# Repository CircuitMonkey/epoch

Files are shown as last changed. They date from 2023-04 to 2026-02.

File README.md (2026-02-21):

# Epoch 1
A 16 channel hand-held vibrator controller (haptic field emitter). With LCD Touch Screen and SD Card reader. Replaced by [Epoch-2](https://github.com/CircuitMonkey/epoch-2)

## Features
 - TFT Touch Display - 320x240 - 3.2inch - SPI Type - Resistive Touch
 - Adafruit Huzzah32 ESP Controller Board (#3405)
 - TLC59401RHB SPI PWM Channel Driver
 - LiPo Battery - 62mm x 50mm, 2500mAH, Adafruit (#328)
 - Molex MiniFitJr type connectors with custom cables.
 - Programmed in Arduino
 - Approximate size of original Apple iPod.

## Dev Notes
 - Huzzah has on-board LiPo charger which made integration simple.
 - Choice of Molex MinifitJr type connectors was cumbersome in use.
 - Choice of Molex MinifitJr type connectors made custom cable fabrication time consuming.
 - This platform performed well for almost a year, before Epoch-2 developed.
 - Never used SD card. Removed off future designs.
 - Choice of TLC59401RHB was cumbersome in coding. Moved to I2C type PWM chip in future Epoch designs.
 - Choice of TLC59401RHB limited motor size as only could source 120mA per channel. Added power FETs to future Epoch designs.

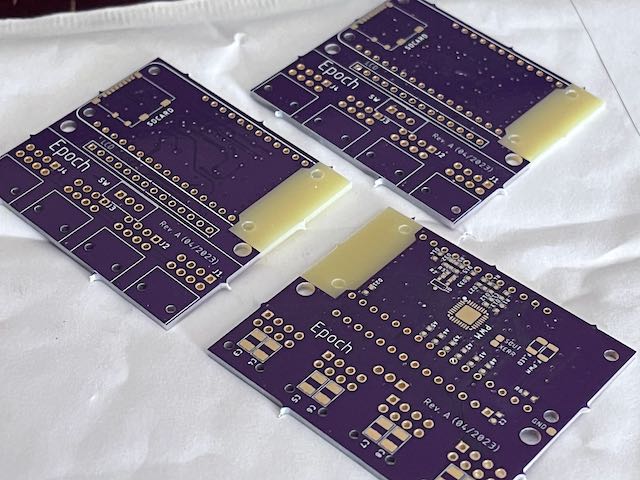
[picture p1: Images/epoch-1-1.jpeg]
Epoch 1 - PCBs (from OshPark.com)

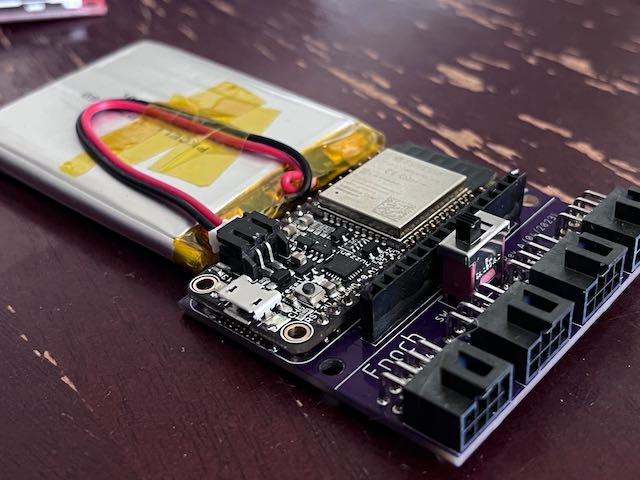
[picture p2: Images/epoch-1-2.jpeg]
Epoch 1 - Board and Battery

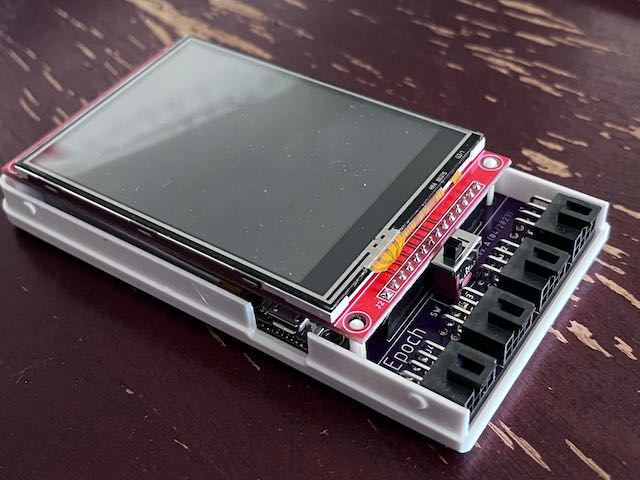
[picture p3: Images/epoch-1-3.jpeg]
Epoch 1 - Board, Battery, LCD and Chassis Bottom

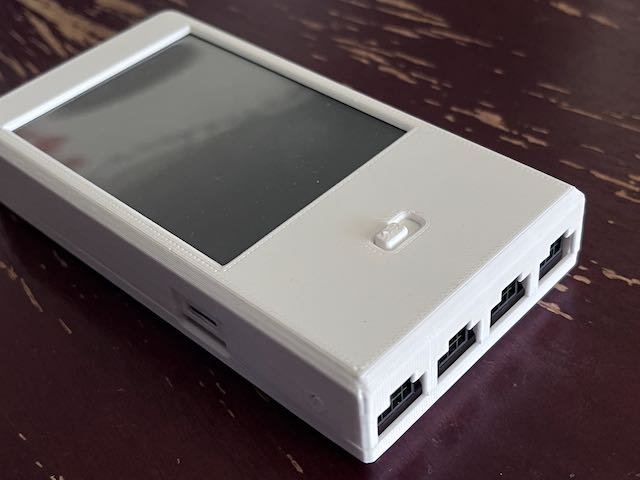
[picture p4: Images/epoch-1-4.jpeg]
Epoch 1 - Assembled Unit

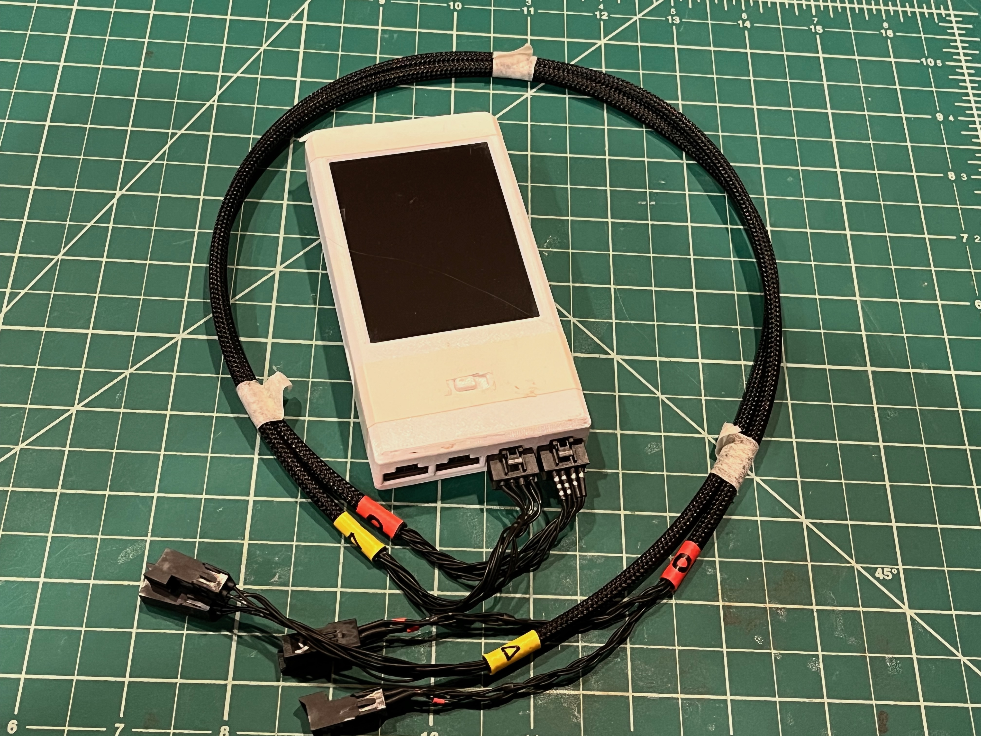
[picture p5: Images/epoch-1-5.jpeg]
Epoch 1 - Assembled Unit with Cables

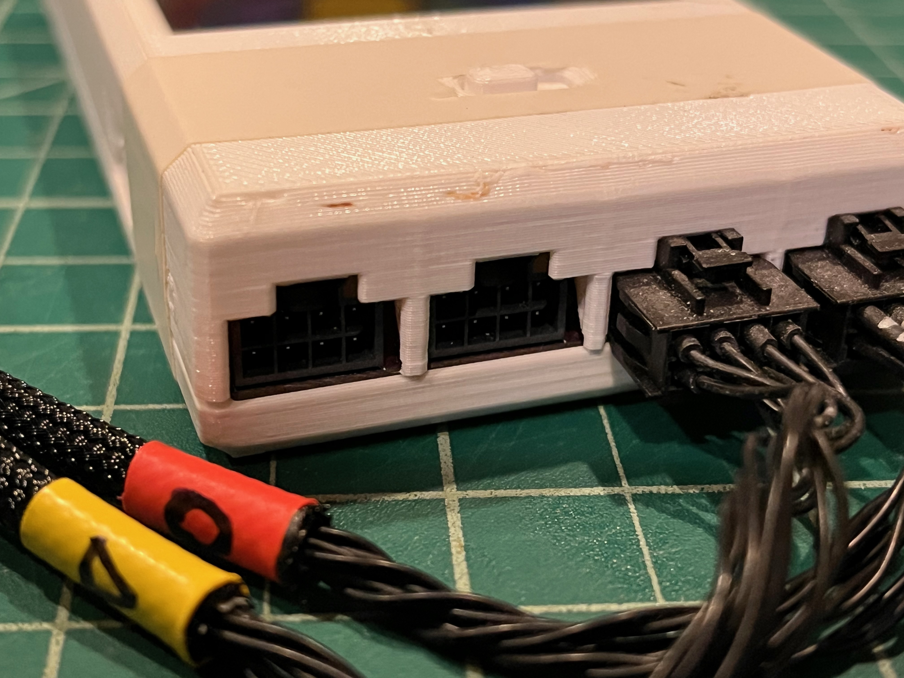
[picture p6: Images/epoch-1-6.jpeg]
Epoch 1 - Connectors Detail

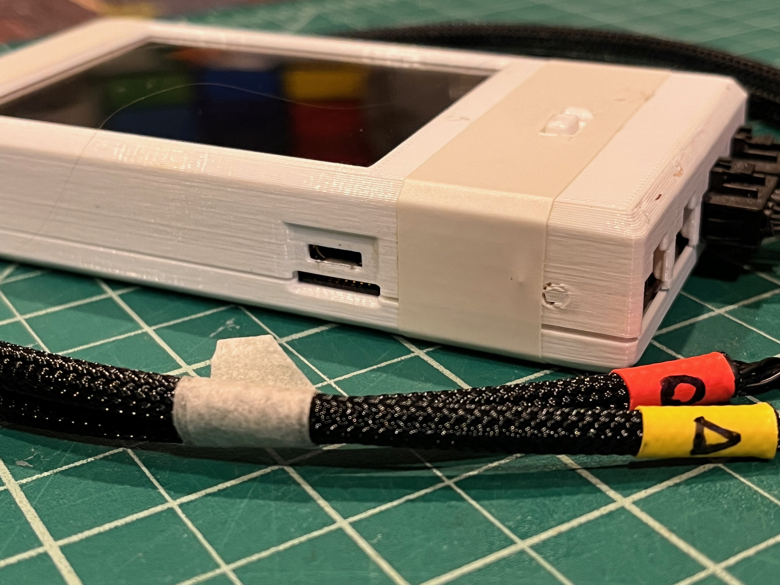
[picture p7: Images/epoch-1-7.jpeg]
Epoch 1 - USB and SC-Card Slot

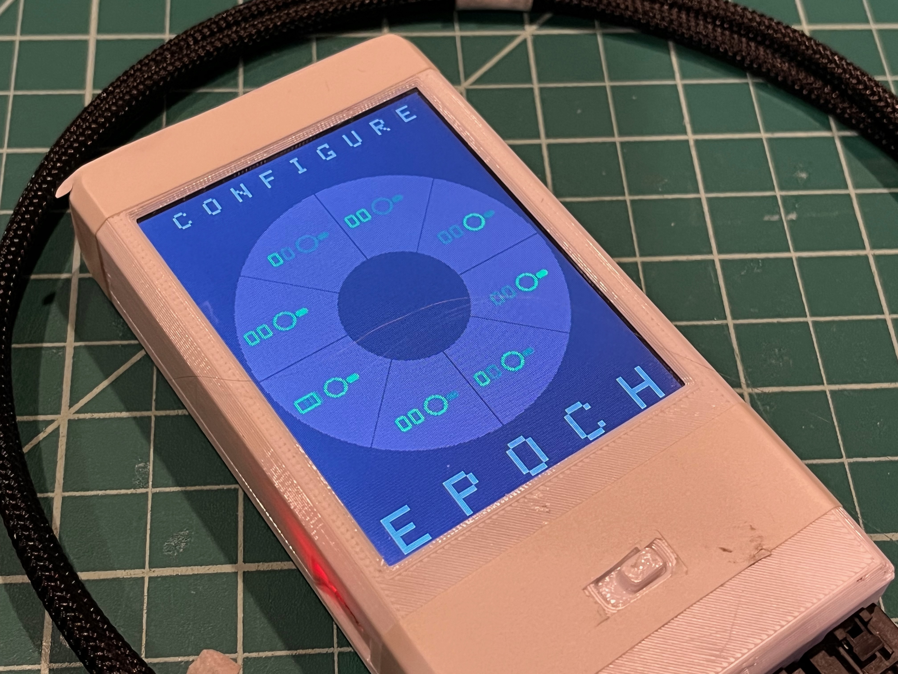
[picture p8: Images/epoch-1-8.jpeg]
Epoch 1 - Configuration Screen

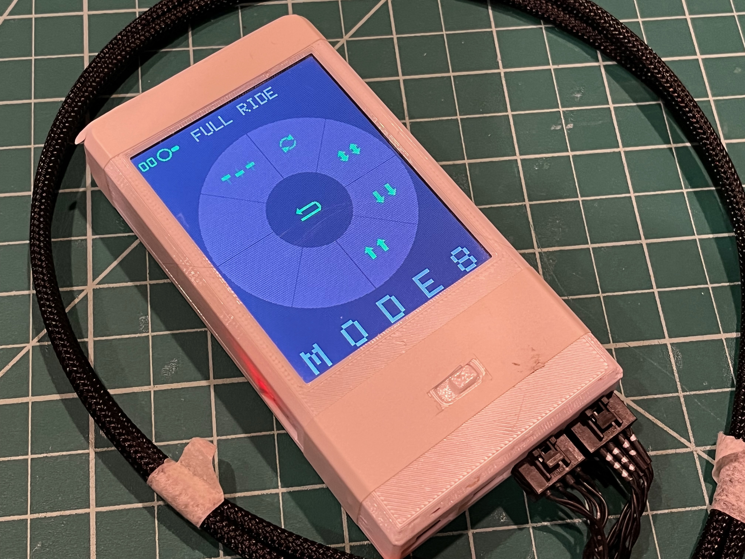
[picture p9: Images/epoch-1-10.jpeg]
Epoch 1 - Mode Selection

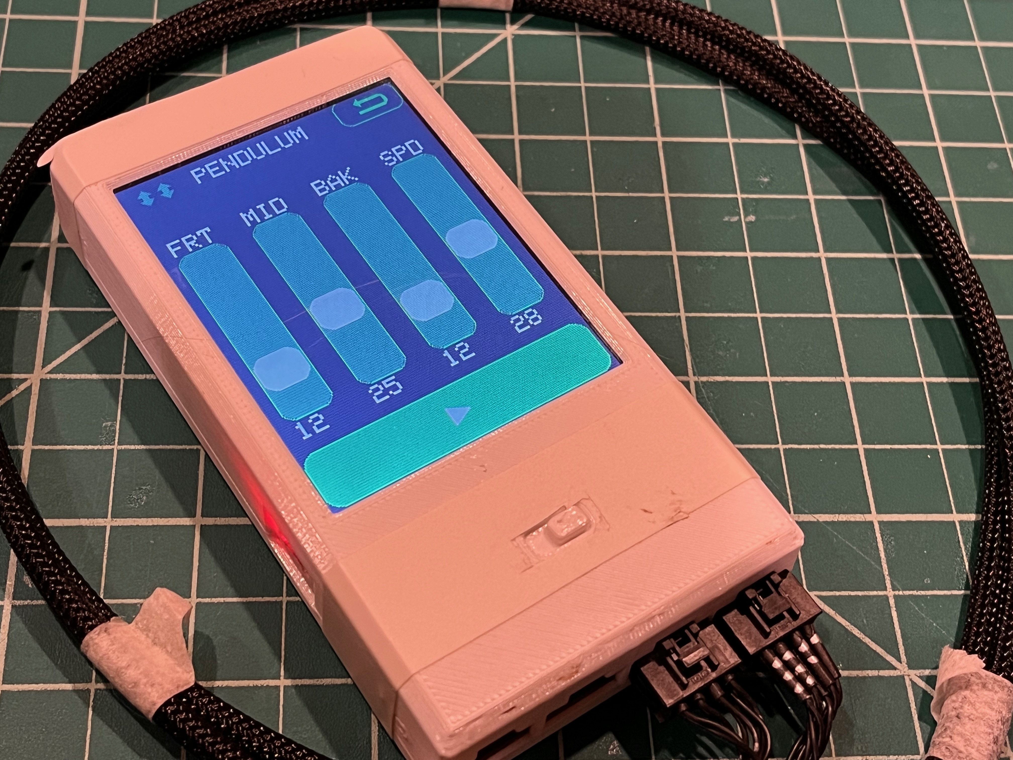
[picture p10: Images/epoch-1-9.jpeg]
Epoch 1 - Pendultum Mode


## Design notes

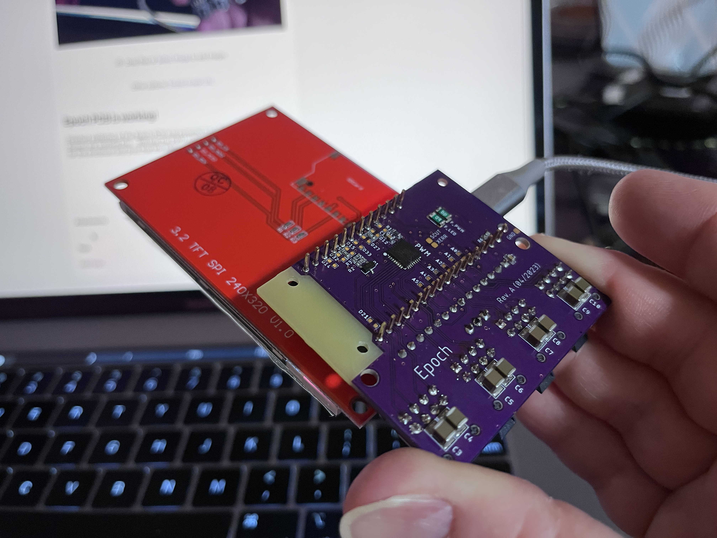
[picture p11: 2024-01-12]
Documents/photos/epoch-bottom-tft.jpeg

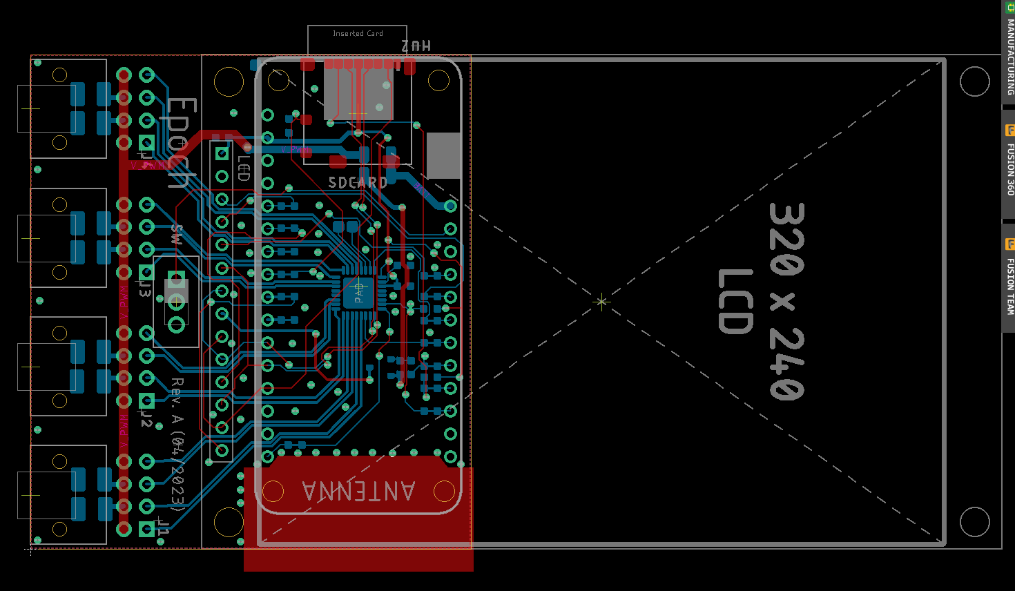
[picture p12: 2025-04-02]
Documents/pcb-layers.png

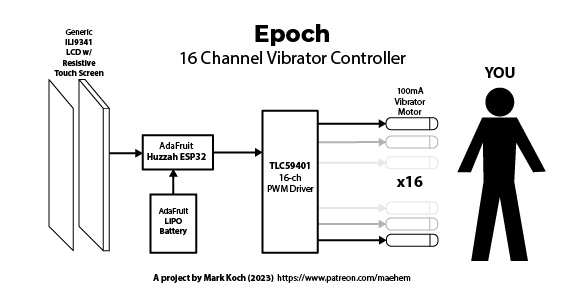
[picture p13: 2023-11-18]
Documents/epoch-block-diagram.png

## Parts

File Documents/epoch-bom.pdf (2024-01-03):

epoch-bom-rev-a

## Circuit Monkey

Epoch – 16-ch Vibe Controller | Rev. A (04/2023)
Part | Value | Package | Description
C1 | 0.1uF | 0603-CAP | Capacitor
C2 | 0.1uF | 0603-CAP | Capacitor
C3 | 22uF/16V | 1210-CAP | Capacitor
C4 | 22uF/16V | 1210-CAP | Capacitor
C5 | 22uF/16V | 1210-CAP | Capacitor
C6 | 22uF/16V | 1210-CAP | Capacitor
C7 | 22uF/16V | 1210-CAP | Capacitor
C8 | 22uF/16V | 1210-CAP | Capacitor
C9 | 22uF/16V | 1210-CAP | Capacitor
C10 | 22uF/16V | 1210-CAP | Capacitor
R1 | 330 | 0603-RES | Resistor
R2 | 100K | 0603-RES | Resistor
R3 | 1K | 0603-RES | Resistor
R4 | 10K | 0603-RES | Resistor
R5 | 100K | 0603-RES | Resistor
R6 | 10K | 0603-RES | Resistor
F_LED | Belfuse 0ZCJxxx | BELFUSE-1206 | Fuse, 100mA
F_PWM | Belfuse 0ZCJxxx | BELFUSE-1206 | Fuse, 750mA
Q1 | P-FET, 20V, 2A | SOT-23 | P-FET (PFET)
PWM | 16-CH PWM Driver QFN-32 | 16-CHANNEL LED DRIVER
J1 | | MOLEX-105314-XX08 | 8-pin, Nanofit, 2-ROW, RA, SMD
J2 | | MOLEX-105314-XX08 | 8-pin, Nanofit, 2-ROW, RA, SMD
J3 | | MOLEX-105314-XX08 | 8-pin, Nanofit, 2-ROW, RA, SMD
J4 | | MOLEX-105314-XX08 | 8-pin, Nanofit, 2-ROW, RA, SMD
LCD-SCKTHeader | Header, 14P, VERT, FEM
SDCARD MOLEX_1040310811MOLEX_1040310811_USD | MICRO-SD
SW | SPDT | CK_TS01C | Switch,Slide, SPDT, PCB
HUZ | Huzzah, ESP32 | ADAFRUIT_HUZZAH32 | AdaFruit Huzzah32
LCD | LCD,320x240,3.2in LCD-320X240-DIANN-3.2 | LCD, 320x240, Touch, 3.2-inch
| | | Parts Cost :

Cables
Conn | Molex Housing, 8P
Wire | Wire with crimped pin

COST01 COST10 COST100 HAVE MFR | MPN
$0.12 | $0.09 | $0.05
$0.12 | $0.09 | $0.05
$0.25 | $0.20 | $0.10
$0.25 | $0.20 | $0.10
$0.25 | $0.20 | $0.10
$0.25 | $0.20 | $0.10
$0.25 | $0.20 | $0.10
$0.25 | $0.20 | $0.10
$0.25 | $0.20 | $0.10
$0.25 | $0.20 | $0.10
$0.10 | $0.05 | $0.02
$0.10 | $0.05 | $0.02
$0.10 | $0.05 | $0.02
$0.10 | $0.05 | $0.02
$0.10 | $0.05 | $0.02
$0.10 | $0.05 | $0.02
$0.22 | $0.14 | $0.10 Mouser | Belfuse | 0ZCJ0010FF2E
$0.25 | $0.23 | $0.19 Mouser | Belfuse | 0ZCJ0075FF2C
$0.45 | $0.35 | $0.25 Mouser | Generic | FDN340P
$3.50 | $3.10 | $2.60 Mouser | Texas Instruments TLC59401RHB
$2.00 | $1.70 | $1.50 Mouser | Molex
$2.00 | $1.70 | $1.50 Mouser | Molex
$2.00 | $1.70 | $1.50 Mouser | Molex
$2.00 | $1.70 | $1.50 Mouser | Molex
$0.30 | $0.20 | $0.10 | Tayda
$2.25 | $1.90 | $1.60 | Molex | 1040310811
$5.00 | $4.00 | $2.00 | C&K | TS01C*
$20.00 | $18.00 | $16.00 Mouser | AdaFruit | 3405
$16.00 | $14.00 | $8.00 | DIANN
$58.81 $50.80 | $37.86
$0.30 | $0.30 | $0.25 | Molex | 105308-1208
$0.19 | $0.19 | $0.16 | Molex | 105300-1200

### LINK

1210/47uF/10V have

### ZXMP3A13FTA

https://www.mouser.com/ProductDetail/Texas-Instruments/TLC59401RHBR

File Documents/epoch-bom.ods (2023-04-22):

Circuit Monkey
Epoch – 16-ch Vibe Controller |  |  | Rev. A (04/2023)
Part | Value | Package | Description | COST01 | COST10 | COST100 | HAVE | MFR | MPN | LINK
C1 | 0.1uF | 0603-CAP | Capacitor | $0.12 | $0.09 | $0.05
C2 | 0.1uF | 0603-CAP | Capacitor | $0.12 | $0.09 | $0.05
C3 | 22uF/16V | 1210-CAP | Capacitor | $0.25 | $0.20 | $0.10
C4 | 22uF/16V | 1210-CAP | Capacitor | $0.25 | $0.20 | $0.10
C5 | 22uF/16V | 1210-CAP | Capacitor | $0.25 | $0.20 | $0.10 |  |  |  | 1210/47uF/10V have
C6 | 22uF/16V | 1210-CAP | Capacitor | $0.25 | $0.20 | $0.10
C7 | 22uF/16V | 1210-CAP | Capacitor | $0.25 | $0.20 | $0.10
C8 | 22uF/16V | 1210-CAP | Capacitor | $0.25 | $0.20 | $0.10
C9 | 22uF/16V | 1210-CAP | Capacitor | $0.25 | $0.20 | $0.10
C10 | 22uF/16V | 1210-CAP | Capacitor | $0.25 | $0.20 | $0.10
R1 | 330 | 0603-RES | Resistor | $0.10 | $0.05 | $0.02
R2 | 100K | 0603-RES | Resistor | $0.10 | $0.05 | $0.02
R3 | 1K | 0603-RES | Resistor | $0.10 | $0.05 | $0.02
R4 | 10K | 0603-RES | Resistor | $0.10 | $0.05 | $0.02
R5 | 100K | 0603-RES | Resistor | $0.10 | $0.05 | $0.02
R6 | 10K | 0603-RES | Resistor | $0.10 | $0.05 | $0.02
F_LED | Belfuse 0ZCJxxx | BELFUSE-1206 | Fuse, 100mA | $0.22 | $0.14 | $0.10 | Mouser | Belfuse | 0ZCJ0010FF2E
F_PWM | Belfuse 0ZCJxxx | BELFUSE-1206 | Fuse, 750mA | $0.25 | $0.23 | $0.19 | Mouser | Belfuse | 0ZCJ0075FF2C
Q1 | P-FET, 20V, 2A | SOT-23 | P-FET (PFET) | $0.45 | $0.35 | $0.25 | Mouser | Generic | FDN340P | ZXMP3A13FTA
PWM | 16-CH PWM Driver | QFN-32 | 16-CHANNEL LED DRIVER | $3.50 | $3.10 | $2.60 | Mouser | Texas Instruments | TLC59401RHB | https://www.mouser.com/ProductDetail/Texas-Instruments/TLC59401RHBR
J1 |  | MOLEX-105314-XX08 | 8-pin, Nanofit, 2-ROW, RA, SMD | $2.00 | $1.70 | $1.50 | Mouser | Molex
J2 |  | MOLEX-105314-XX08 | 8-pin, Nanofit, 2-ROW, RA, SMD | $2.00 | $1.70 | $1.50 | Mouser | Molex
J3 |  | MOLEX-105314-XX08 | 8-pin, Nanofit, 2-ROW, RA, SMD | $2.00 | $1.70 | $1.50 | Mouser | Molex
J4 |  | MOLEX-105314-XX08 | 8-pin, Nanofit, 2-ROW, RA, SMD | $2.00 | $1.70 | $1.50 | Mouser | Molex
LCD-SCKT | Header |  | Header, 14P, VERT, FEM | $0.30 | $0.20 | $0.10 |  | Tayda
SDCARD | MOLEX_1040310811 | MOLEX_1040310811_USD | MICRO-SD | $2.25 | $1.90 | $1.60 |  | Molex | 1040310811
SW | SPDT | CK_TS01C | Switch,Slide, SPDT, PCB | $5.00 | $4.00 | $2.00 |  | C&K | TS01C*
HUZ | Huzzah, ESP32 | ADAFRUIT_HUZZAH32 | AdaFruit Huzzah32 | $20.00 | $18.00 | $16.00 | Mouser | AdaFruit | 3405
LCD | LCD,320x240,3.2in | LCD-320X240-DIANN-3.2 | LCD, 320x240, Touch, 3.2-inch | $16.00 | $14.00 | $8.00 |  | DIANN
 |  |  | Parts Cost : | $58.81 | $50.80 | $37.86
Cables
Conn |  |  | Molex Housing, 8P | $0.30 | $0.30 | $0.25 |  | Molex | 105308-1208
Wire |  |  | Wire with crimped pin | $0.19 | $0.19 | $0.16 |  | Molex | 105300-1200

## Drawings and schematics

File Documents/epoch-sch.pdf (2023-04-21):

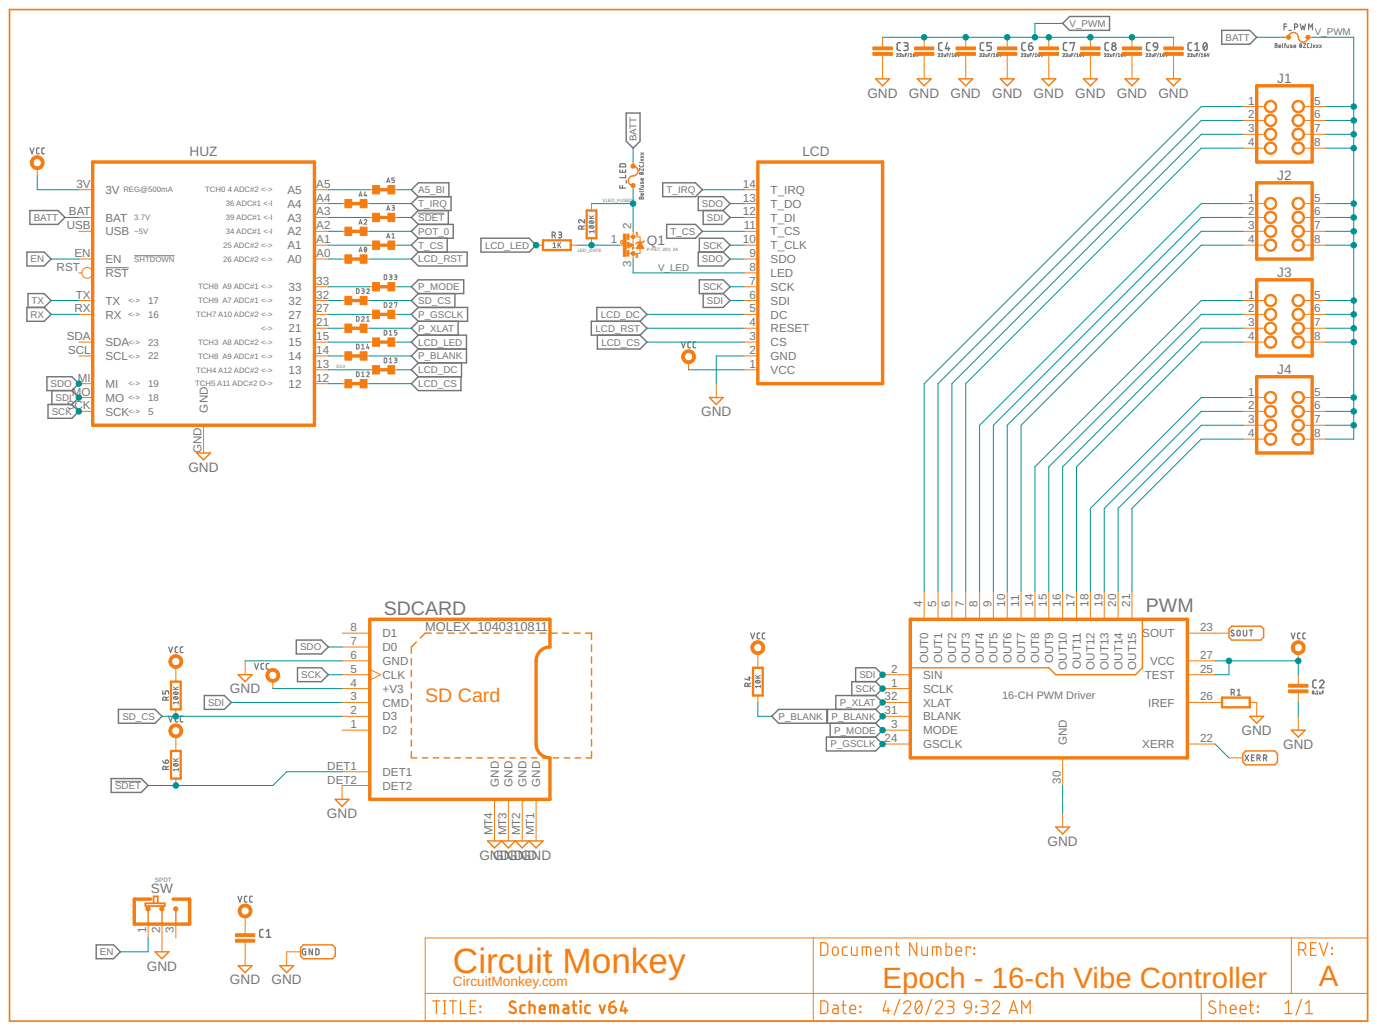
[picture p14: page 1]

GND GND GND GND

34 ADC#1 <-I 39 ADC#1 <-I 36 ADC#1 <-I TCH0 4 ADC#2 <->

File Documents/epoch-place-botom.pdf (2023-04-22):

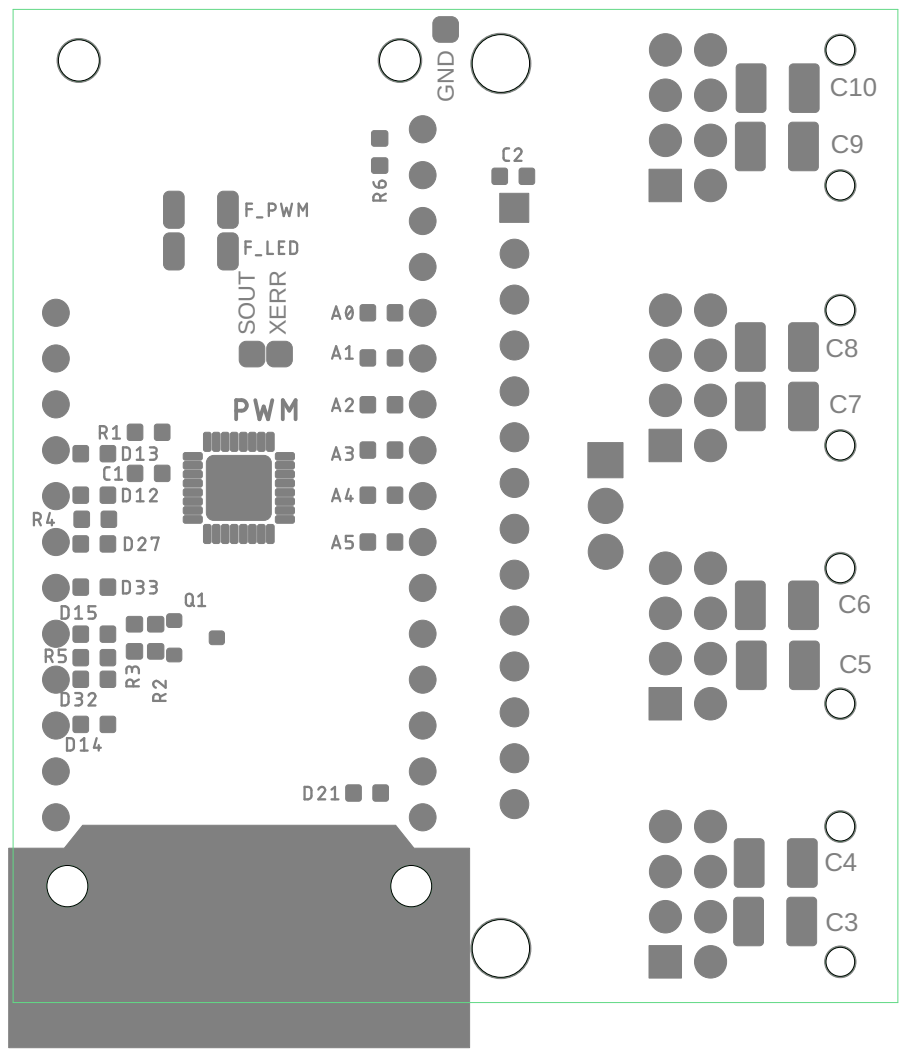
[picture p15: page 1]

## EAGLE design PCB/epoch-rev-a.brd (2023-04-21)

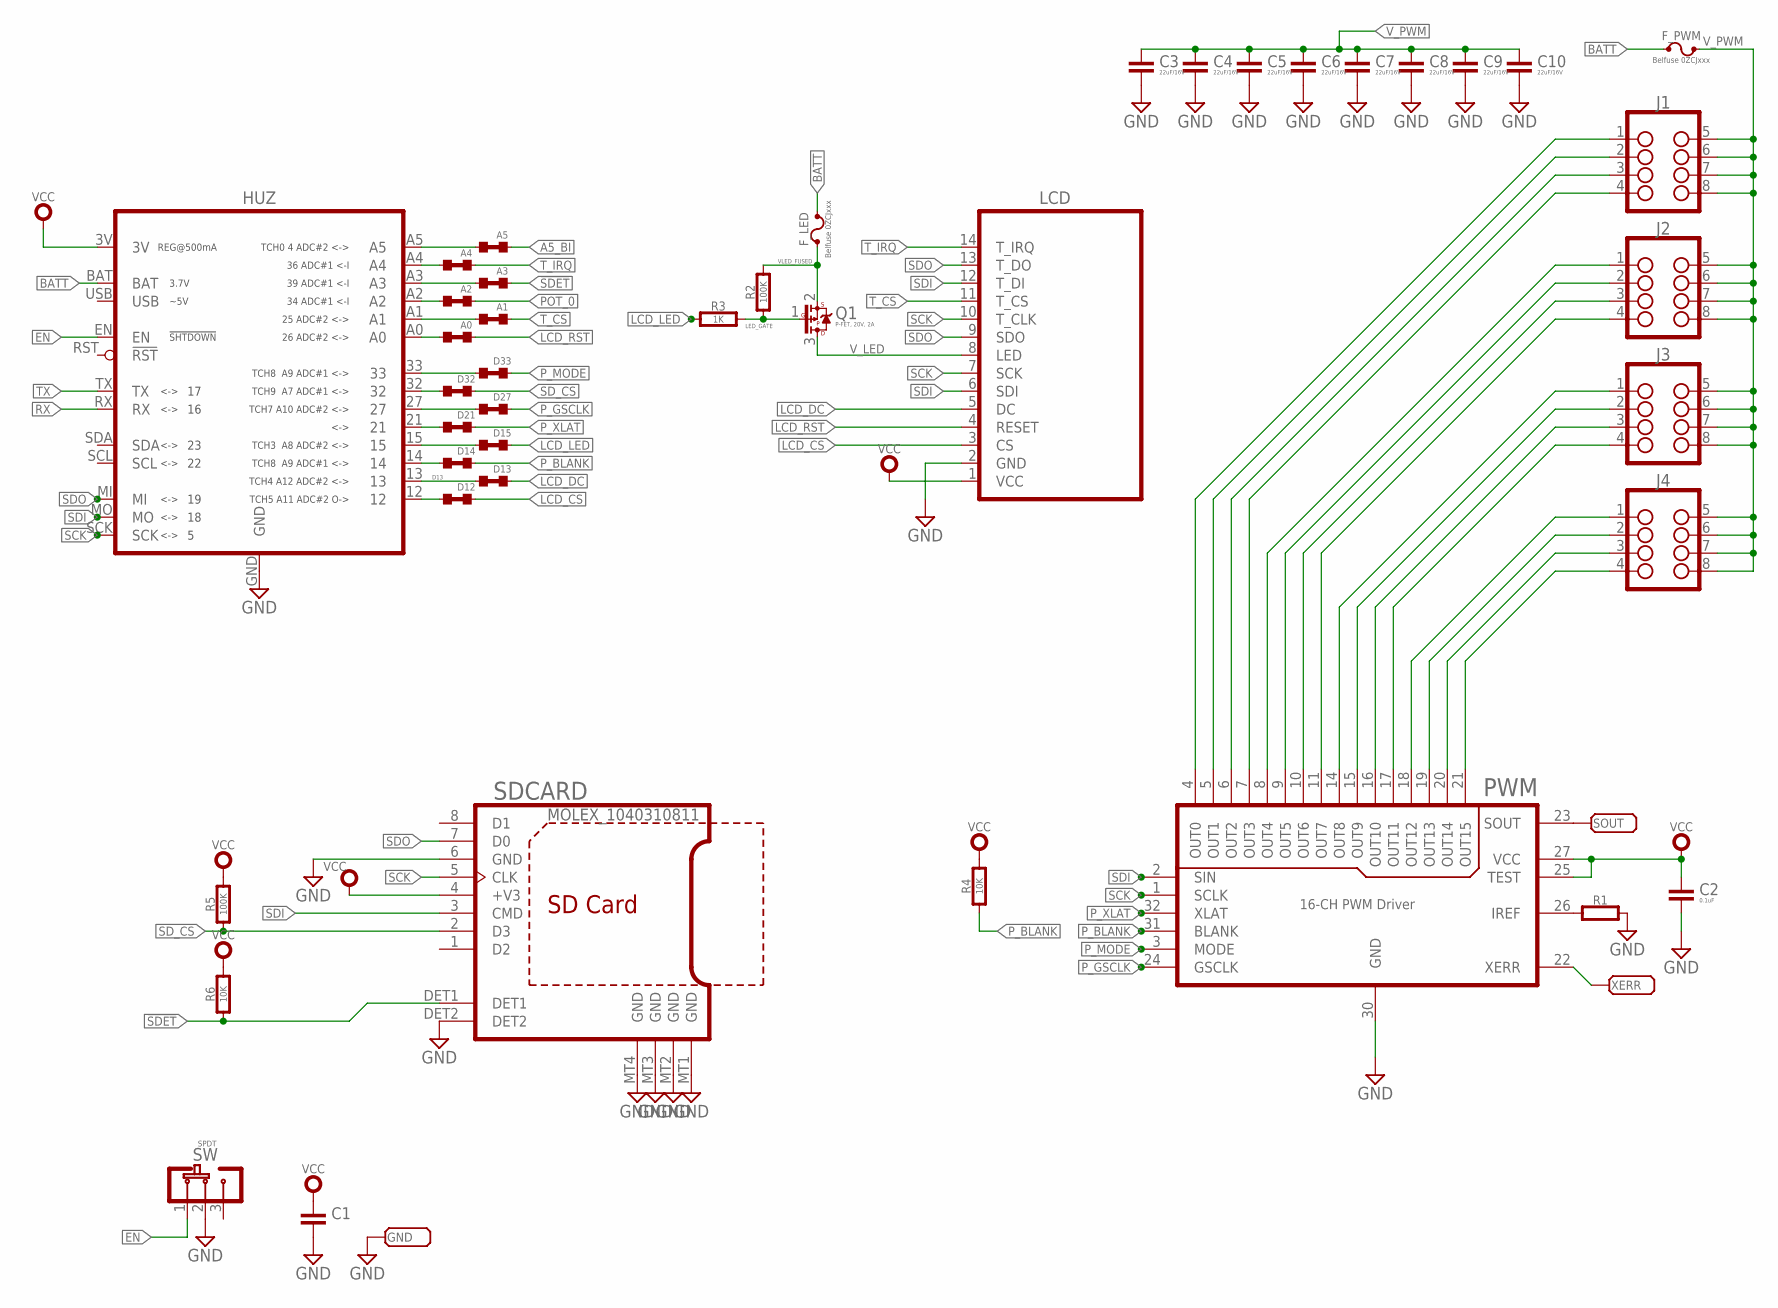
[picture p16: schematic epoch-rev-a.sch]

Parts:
A0, A1, A2, A3, A4, A5: NP; 0603-SHORT
C1: CAPACITOR0603; 0603-CAP
C2: 0.1uF; 0603-CAP
C3, C4, C5, C6, C7, C8, C9, C10: 22uF/16V; 1210-CAP
D12, D13, D14, D15, D21, D27, D32, D33: NP; 0603-SHORT
F_LED: Belfuse 0ZCJxxx; BELFUSE-1206
F_PWM: Belfuse 0ZCJxxx; BELFUSE-1206
GND: PADSMD-050X050; SMD-050X050
HUZ: HUZZAHHUZZAH; ADAFRUIT_HUZZAH32
J1, J2, J3, J4: NANOFIT-08P-DR-RA-THD; MOLEX-105314-XX08
LCD: LCD-320X240-3.2-INCH-SPI-DIANN-LOWPROFILE; LCD-320X240-DIANN-3.2-LP-SOCKET
PWM: 16-CH PWM Driver; QFN-32
Q1: P-FET, 20V, 2A; SOT-23
R1: RESISTOR0603; 0603-RES
R2, R5: 100K; 0603-RES
R3: 1K; 0603-RES
R4, R6: 10K; 0603-RES
SDCARD: MOLEX_1040310811; MOLEX_1040310811_USD
SOUT: PADSMD-050X050; SMD-050X050
SW: SPDT; CK_TS01C
XERR: PADSMD-050X050; SMD-050X050

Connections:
!SDET: A3.4 (2), R6.1, SDCARD.DET1
A5_BI: A5.4 (2)
BATT: F_LED.2, F_PWM.1, HUZ.BAT
D12: D12.3 (1), HUZ.12
D13: D13.3 (1), HUZ.13
D14: D14.3 (1), HUZ.14
D15: D15.3 (1), HUZ.15
EN: HUZ.EN, SW.1 (A)
GND: C1.2, C2.2, C3.2, C4.2, C5.2, C6.2, C7.2, C8.2, C9.2, C10.2, GND.1, HUZ.GND, LCD.2 (GND), PWM.30 (GND), R1.2, SDCARD.6 (GND), SDCARD.DET2, SDCARD.MT1 (GND), SDCARD.MT2 (GND), SDCARD.MT3 (GND), SDCARD.MT4 (GND), SW.2 (C)
LCD_CS: D12.4 (2), LCD.3 (CS)
LCD_DC: D13.4 (2), LCD.5 (DC)
LCD_LED: D15.4 (2), R3.1
LCD_RST: A0.4 (2), LCD.4 (RESET)
LED_GATE: Q1.1 (G), R2.1, R3.2
unnamed: J4.4, PWM.21 (OUT15)
unnamed: J4.3, PWM.20 (OUT14)
unnamed: J4.2, PWM.19 (OUT13)
unnamed: J4.1, PWM.18 (OUT12)
unnamed: J3.4, PWM.17 (OUT11)
unnamed: J3.3, PWM.16 (OUT10)
unnamed: J3.2, PWM.15 (OUT9)
unnamed: J3.1, PWM.14 (OUT8)
unnamed: J2.4, PWM.11 (OUT7)
unnamed: J2.3, PWM.10 (OUT6)
unnamed: J2.2, PWM.9 (OUT5)
unnamed: J2.1, PWM.8 (OUT4)
unnamed: J1.4, PWM.7 (OUT3)
unnamed: J1.3, PWM.6 (OUT2)
unnamed: J1.2, PWM.5 (OUT1)
unnamed: J1.1, PWM.4 (OUT0)
unnamed: PWM.26 (IREF), R1.1
unnamed: PWM.22 (XERR), XERR.1
unnamed: PWM.23 (SOUT), SOUT.1
unnamed: D21.3 (1), HUZ.21
unnamed: D27.3 (1), HUZ.27
unnamed: D32.3 (1), HUZ.32
unnamed: D33.3 (1), HUZ.33
unnamed: A0.3 (1), HUZ.A0
unnamed: A1.3 (1), HUZ.A1
unnamed: A2.3 (1), HUZ.A2
unnamed: A3.3 (1), HUZ.A3
unnamed: A4.3 (1), HUZ.A4
unnamed: A5.3 (1), HUZ.A5
POT_0: A2.4 (2)
P_BLANK: D14.4 (2), PWM.31 (BLANK), R4.1
P_GSCLK: D27.4 (2), PWM.24 (GSCLK)
P_MODE: D33.4 (2), PWM.3 (MODE)
P_XLAT: D21.4 (2), PWM.32 (XLAT)
RX: HUZ.RX
SCK: HUZ.SCK, LCD.7 (SCK), LCD.10 (T_CLK), PWM.1 (SCLK), SDCARD.5 (CLK)
SDI: HUZ.MO, LCD.6 (SDI), LCD.12 (T_DI), PWM.2 (SIN), SDCARD.3 (CMD)
SDO: HUZ.MI, LCD.9 (SDO), LCD.13 (T_DO), SDCARD.7 (D0)
SD_CS: D32.4 (2), R5.1, SDCARD.2 (D3)
TX: HUZ.TX
T_CS: A1.4 (2), LCD.11 (T_CS)
T_IRQ: A4.4 (2), LCD.14 (T_IRQ)
VCC: C1.1, C2.1, HUZ.3V, LCD.1 (VCC), PWM.25 (TEST), PWM.27 (VCC), R4.2, R5.2, R6.2, SDCARD.4 (+V3)
VLED_FUSED: F_LED.1, Q1.2 (S), R2.2
V_LED: LCD.8 (LED), Q1.3 (D)
V_PWM: C3.1, C4.1, C5.1, C6.1, C7.1, C8.1, C9.1, C10.1, F_PWM.2, J1.5, J1.6, J1.7, J1.8, J2.5, J2.6, J2.7, J2.8, J3.5, J3.6, J3.7, J3.8, J4.5, J4.6, J4.7, J4.8

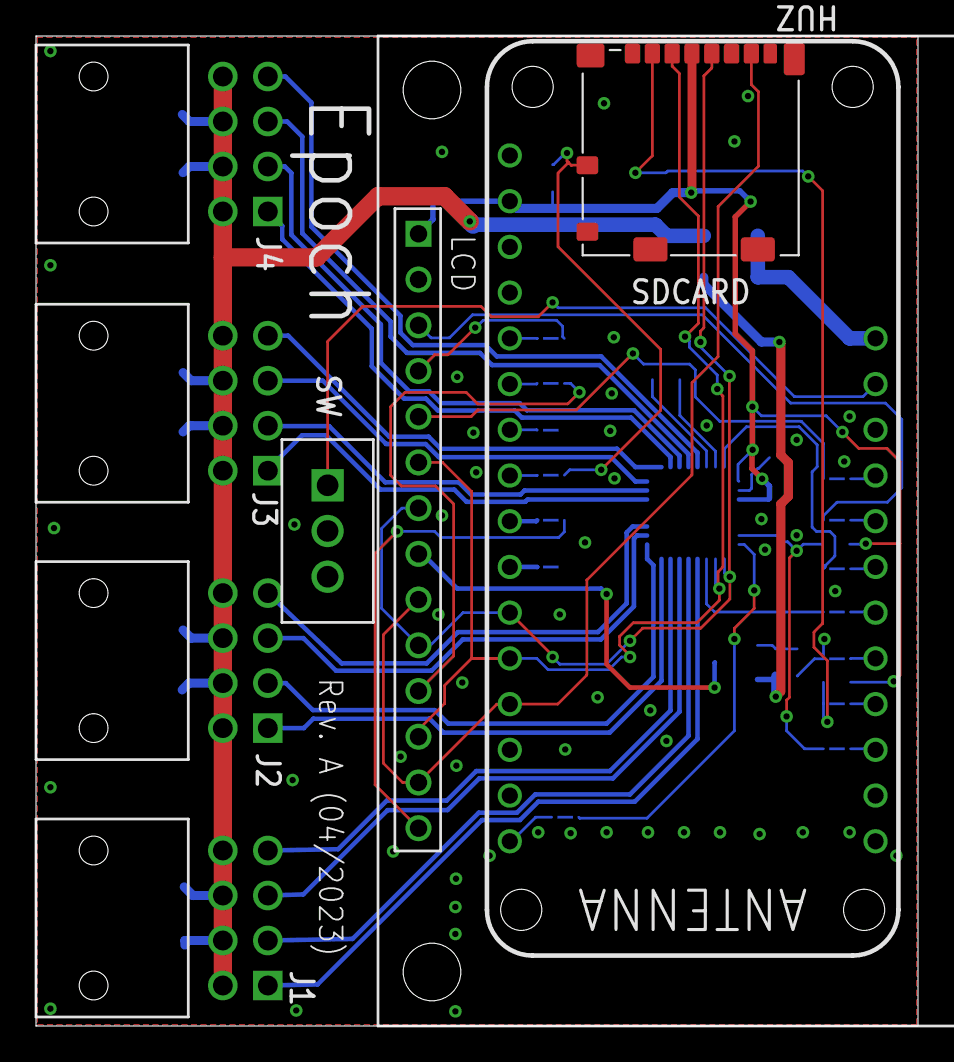
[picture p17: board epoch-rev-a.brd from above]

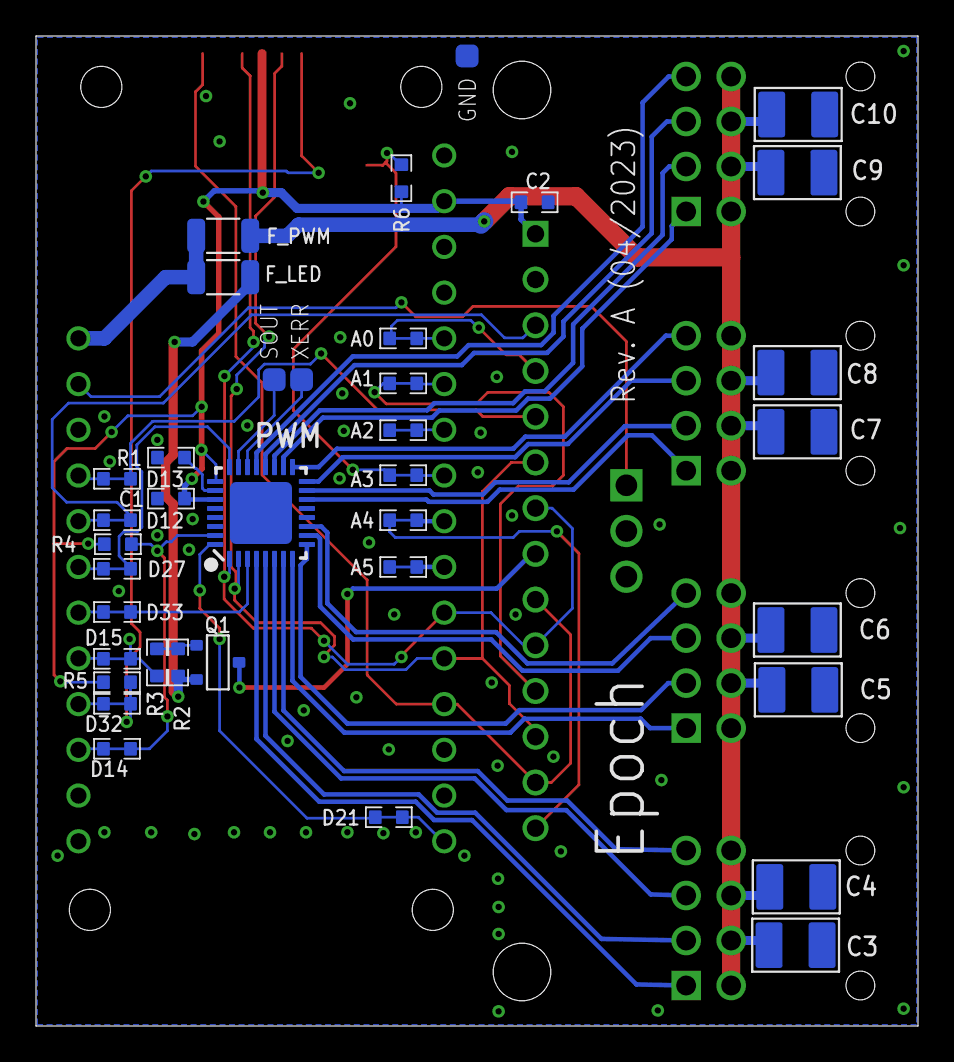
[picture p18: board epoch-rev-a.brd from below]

Board: 2 copper layers, 49.0 x 55.0 mm, 45 parts (37 on the bottom side), 56 nets.

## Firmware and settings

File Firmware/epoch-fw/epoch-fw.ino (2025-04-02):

/**
 Epoch Project - A 16-channel vibrator controller
 with touch screen by Mark J. Koch.
        https://www.patreon.com/maehem

 * * * * * * * * * * * * * * * * * * * * * * * * * * * * * * * * * * *
 Uses code from AdaFruit and Paul Stoffregen
  This is our GFX example for the Adafruit ILI9341 Breakout and Shield
  ----> http://www.adafruit.com/products/1651

  Check out the links above for our tutorials and wiring diagrams
  These displays use SPI to communicate, 4 or 5 pins are required to
  interface (RST is optional)
  Adafruit invests time and resources providing this open source code,
  please support Adafruit and open-source hardware by purchasing
  products from Adafruit!

  Portions Written by Limor Fried/Ladyada for Adafruit Industries.
  MIT license, all text above must be included in any redistribution
 *********************************************************************/

#include "SPI.h"
#include "Adafruit_GFX.h"
#include "Adafruit_ILI9341.h"
#include "XPT2046_Touchscreen.h"
#include "tlc59401.h"
#include "glyphs.h"
#include "ui.h"
#include "slider.h"

// ILI9341 TFT Display
#define TFT_DC 13
#define TFT_CS 12
#define TFT_MOSI 18
#define TFT_MISO 19
#define TFT_CLK 5
#define TFT_RST A0
#define TFT_LED 15

// Touch
#define TCH_CS A1
#define TCH_IRQ A4

// Motor Chip
#define VIB_MODE 33
#define VIB_BLANK 14
#define VIB_GSCLK 27
#define VIB_XLAT 21

#define VIB_PI 3.142f

//#define SPI_DEFAULT_FREQ 2000000
//#define SPI_SETTING     SPISettings(2000000, MSBFIRST, SPI_MODE0)

// Use hardware SPI (on Uno, #13, #12, #11) and the above for CS/DC
Adafruit_ILI9341 tft = Adafruit_ILI9341(TFT_CS, TFT_DC);
// If using the breakout, change pins as desired
//Adafruit_ILI9341 tft = Adafruit_ILI9341(TFT_CS, TFT_DC, TFT_MOSI, TFT_CLK, TFT_RST, TFT_MISO);
XPT2046_Touchscreen ts(TCH_CS);
//XPT2046_Touchscreen ts(TCH_CS,TCH_IRQ);
TLC59401_PWM vibes = TLC59401_PWM(VIB_MODE, VIB_BLANK, VIB_GSCLK, VIB_XLAT);

Ui ui = Ui();

boolean wastouched = false;
boolean istouched = false;
TS_Point p;
TS_Point pLast;
TS_Point pDragStart;
uint8_t slideDragStart;
uint8_t lastBtn = 99;
uint8_t guiMode = 0;
bool updateSemaphore = false;

hw_timer_t *Timer0_Cfg = NULL;
portMUX_TYPE timerMux0 = portMUX_INITIALIZER_UNLOCKED;

void IRAM_ATTR Timer0_ISR() {
  // Set semaphore.
  updateSemaphore = true;
}

void setup() {
  Serial.begin(115200);
  while (!Serial) delay(10);
  delay(500);
  Serial.flush();
  Serial.println("\n\nEpoch Haptic Generator");

  pinMode(TFT_LED, OUTPUT);
  digitalWrite(TFT_LED, HIGH);
  pinMode(TFT_RST, OUTPUT);
  digitalWrite(TFT_RST, LOW);
  delay(30);
  digitalWrite(TFT_RST, HIGH);

  tft.begin();
  ts.begin();
  ts.setRotation(2);  // X/Y==0 top-left.
  vibes.begin();  // vibes assume SPI was set up by TFT

//#elif (RH_PLATFORM == RH_PLATFORM_ESP32)
//     void RH_INTERRUPT_ATTR esp32_timer_interrupt_handler(); // Forward declaration
//     timer = timerBegin(0, 80, true); // Alarm value will be in in us
//     timerAttachInterrupt(timer, &esp32_timer_interrupt_handler, true);
//     timerAlarmWrite(timer, 1000000 / _speed / 8, true);
//     timerAlarmEnable(timer);
// #endif

//#elif (RH_PLATFORM == RH_PLATFORM_ESP32)
//    void RH_INTERRUPT_ATTR esp32_timer_interrupt_handler(); // Forward declaration
//    timer = timerBegin(1000000);
//    timerAttachInterrupt(timer, &esp32_timer_interrupt_handler);
//    timerAlarm(timer, 1000000 / _speed / 8, true, 0);
//#endif

  // Set up motor update clock.
  // OLD
  //Timer0_Cfg = timerBegin(1, 80, true);  // channel 1, prescaler 80 (80/80MHz =  1MHz), tick count up.
  //timerAttachInterrupt(Timer0_Cfg, &Timer0_ISR, true);
  //timerAlarmWrite(Timer0_Cfg, 100000, true);  // doISR every 100000 ticks = 100mS
  ////timerAlarmWrite(Timer0_Cfg, 17000, true);  // doISR every 17000 ticks = 17mS
  //timerAlarmEnable(Timer0_Cfg);

  // NEW
    Timer0_Cfg = timerBegin(1000000);
    timerAttachInterrupt(Timer0_Cfg, &Timer0_ISR);
    timerAlarm(Timer0_Cfg, 100000, true, 0);

  vibes.pause(true);

  digitalWrite(TFT_LED, LOW); // TFT backlight on
  // TODO:  PWM LED brightness

  //printTftSettings();  // For TFT diagnostics info

  ui.begin(&tft, glyph48m_back, glyph48m_pause, glyph48m_play );
  mode_0_start();
}


void loop() {
  istouched = ts.touched();
  p = p2lcd(ts.getPoint());
  switch (guiMode) {
    case 0:
      mode_0_loop();
      break;
    case 1:  // Single ring.
      mode_1_loop();
      break;
    case 2:
      mode_2_loop();
      break;
    case 4:
      mode_4_loop();
      break;
    case 7:
      mode_7_loop();
      break;
    case 8:
      mode_8_loop();
      break;
    case 77: // OLD Debug code.  Not used.
      if (istouched) {
        if (!wastouched) {
          tft.fillScreen(ILI9341_BLACK);
          //tft.setTextColor(ILI9341_YELLOW);
          //tft.setFont(Arial_60);
          tft.setTextColor(ILI9341_GREEN);
          tft.setTextSize(1);
          tft.setCursor(60, 80);
          tft.print("Touch");
          Serial.print("New Touch...");
        }
        tft.fillRect(100, 150, 100, 40, ILI9341_BLACK);
        tft.setTextSize(1);
        tft.setTextColor(ILI9341_GREEN);
        //tft.setFont(Arial_24);
        tft.setCursor(100, 150);
        tft.print("X = ");
        tft.print(p.x);
        tft.setCursor(100, 180);
        tft.print("Y = ");
        tft.print(p.y);
        Serial.print(" x = ");
        Serial.print(p.x);
        Serial.print(", y = ");
        Serial.println(p.y);
      } else {
        if (wastouched) {
          tft.fillScreen(ILI9341_BLACK);
          tft.setTextColor(ILI9341_RED);
          //tft.setFont(Arial_48);
          tft.setCursor(120, 50);
          tft.print("No...");
          tft.setCursor(80, 120);
          tft.print("Touch");
        }
      }
      wastouched = istouched;
      delay(70);
  }
  pLast.x = p.x;
  pLast.y = p.y;

  if ( updateSemaphore ) {
    switch( guiMode ) {
      case 0:
        mode_0_updateMotors();
        break;
      case 1:
        mode_1_updateMotors();
        break;
      case 2:
        mode_2_updateMotors();
        break;
      case 4:
        mode_4_updateMotors();
        break;
      case 7:
        mode_7_updateMotors();
        break;
      case 8:
        mode_8_updateMotors();
    }
    //vibes.update();
    updateSemaphore = false;
  }
}

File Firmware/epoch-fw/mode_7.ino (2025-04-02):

/**
 * Mode 7 - Tripple Haptic Element Pair
 * 
 * Six Vibrators: (Rumble Size x2 on Channel A, current bonded)
 *       (Left - Right):A,                    Connector A, Channel 1+2 and 3+4
 *       (Left - Right):A, (Foward - Back):B  Connector B, Channel 1-4
 */

// Mode 7. Dual Haptic Element Pair
// Mode 7 functions: 0:Back to Main menu,  1:Sliders, 2:Cycle, 3:Pendulum, 4:Plunge, 5:Draw Out
uint8_t mode_7_function = 0;

Slider m_7_1_slider[4] = {
  Slider("TIP", SLIDER_4_X1, 5, 63),
  Slider("MID", SLIDER_4_X2, 9, 63),
  Slider("ANS", SLIDER_4_X3, 14, 63),
  Slider("END", SLIDER_4_X4, 18, 63)
};
Slider m_7_2_slider[4] = {  // cycle func
  Slider("FRT", SLIDER_4_X1, 12, 63),
  Slider("MID", SLIDER_4_X2, 25, 63),
  Slider("BAK", SLIDER_4_X3, 12, 63),
  Slider("SPD", SLIDER_4_X4, 28, 63)
};
Slider m_7_3_slider[4] = {  // pendulum func
  Slider("FRT", SLIDER_4_X1, 12, 63),
  Slider("MID", SLIDER_4_X2, 25, 63),
  Slider("BAK", SLIDER_4_X3, 12, 63),
  Slider("SPD", SLIDER_4_X4, 28, 63)
};
Slider m_7_4_slider[4] = {  // plunge func
  Slider("FRT", SLIDER_4_X1, 12, 63),
  Slider("MID", SLIDER_4_X2, 20, 63),
  Slider("BAK", SLIDER_4_X3, 28, 63),
  Slider("SPD", SLIDER_4_X4, 4, 14)
};
Slider m_7_5_slider[4] = {  // draw func
  Slider("FRT", SLIDER_4_X1, 12, 63),
  Slider("MID", SLIDER_4_X2, 20, 63),
  Slider("BAK", SLIDER_4_X3, 28, 63),
  Slider("SPD", SLIDER_4_X4, 4, 14)
};
float mode_7_2_cycle = 0.0;  // in Radians 0 - 6.283
#define MODE_7_2_CYC_MAX 10.0f
#define MODE_7_2_CYC_MIN 0.4f

float mode_7_3_cycle = 0.0;  // in Radians 0 - 6.283
#define MODE_7_3_CYC_MAX 10.0f
#define MODE_7_3_CYC_MIN 0.4f

uint8_t mode_7_4_cycle = 0;  // in ticks 0 - 64
#define MODE_7_4_CYC_MAX 63
//#define MODE_7_4_CYC_MIN 12

float mode_7_5_cycle = 0.0;  // in Radians 0 - 6.283
#define MODE_7_5_CYC_MAX 63
#define MODE_7_5_CYC_MIN 8

// back button is at index 0.
const unsigned char *m_7_0_glyphs_bg[9] = { glyph48m_back, glyph48m_slide_bg, glyph48m_cycle, glyph48m_pendulum, glyph48m_plunge, glyph48m_draw, glyph48m_blank, glyph48m_blank, glyph48m_blank };
const unsigned char *m_7_0_glyphs_fg[9] = { glyph48m_back, glyph48m_slide_fg, glyph48m_cycle, glyph48m_pendulum, glyph48m_plunge, glyph48m_draw, glyph48m_blank, glyph48m_blank, glyph48m_blank };

void mode_7_updateMotors() {
  switch (mode_7_function) {
    // Other cases handled during drag.
    case 1:
      mode_7_1_update_motors();
      break;
    case 2:
      mode_7_2_update_motors();
      break;
    case 3:
      mode_7_3_update_motors();
      break;
    case 4:
      mode_7_4_update_motors();
      break;
    case 5:
      mode_7_5_update_motors();
      break;
  }
  vibes.update();
}

void mode_7_0_start() {
  ui.setStyleDisc("  RUMBLE   ", "M O D E 7", glyph48m_vibe_8, glyph48m_vibe_7, m_7_0_glyphs_bg, m_7_0_glyphs_fg);

  // TODO: Set based on UI pause mode.
  vibes.pause(true);
}

void mode_7_1_start() {
  ui.setStyleSlide4("SLIDERS", glyph48m_slide_bg, glyph48m_slide_fg);

  for (int i = 0; i < 4; i++) {
    m_7_1_slider[i].begin(&tft);
    vibes.set(i, m_7_1_slider[i].getVal());
  }
  vibes.pack();  // do whenever you call one or more vibes.set()

  // TODO: ask UI for play mode and set appropriately.
  vibes.pause(true);
}

/**
 * cycle functions
 */
void mode_7_2_start() {
  ui.setStyleSlide4("CYCLE", glyph48m_cycle, NULL);

  for (int i = 0; i < 4; i++) {
    m_7_2_slider[i].begin(&tft);
    vibes.set(i, m_7_2_slider[i].getVal());
  }

  vibes.pack();  // do whenever you call one or more vibes.set()

  // TODO: ask UI for play mode and set appropriately.
  vibes.pause(true);
}

/**
 * pendulum functions
 */
void mode_7_3_start() {
  ui.setStyleSlide4("PENDULUM", glyph48m_pendulum, NULL);

  for (int i = 0; i < 4; i++) {
    m_7_3_slider[i].begin(&tft);
    vibes.set(i, m_7_3_slider[i].getVal());
  }

  vibes.pack();  // do whenever you call one or more vibes.set()

  // TODO: ask UI for play mode and set appropriately.
  vibes.pause(true);
}

/**
 * plunge functions
 */
void mode_7_4_start() {
  ui.setStyleSlide4("PLUNGE", glyph48m_plunge, NULL);

  for (int i = 0; i < 4; i++) {
    m_7_4_slider[i].begin(&tft);
    vibes.set(i, m_7_4_slider[i].getVal());
  }

  vibes.pack();  // do whenever you call one or more vibes.set()

  // TODO: ask UI for play mode and set appropriately.
  vibes.pause(true);
}

/**
 * draw functions
 */
void mode_7_5_start() {
  ui.setStyleSlide4("DRAW", glyph48m_draw, NULL);

  for (int i = 0; i < 4; i++) {
    m_7_5_slider[i].begin(&tft);
    vibes.set(i, m_7_5_slider[i].getVal());
  }

  vibes.pack();  // do whenever you call one or more vibes.set()

  // TODO: ask UI for play mode and set appropriately.
  vibes.pause(true);
}

void mode_7_loop() {
  if (istouched) {
    if (!wastouched) {  // New touch
      pDragStart.x = p.x;
      pDragStart.y = p.y;
      //Serial.printf("Mode 8 touch: %d\n", ui.getItemPressed(p));
      switch (mode_7_function) {                      // Handle menu
        case 0:                                       // Mode 0 top menu
          mode_7_0_handle_btn(ui.getItemPressed(p));  // will change the mode or function.
          break;
        case 1:  // mode 0 - init handle sliders or back btn
          mode_7_1_handle_touch(ui.getItemPressed(p));
          break;
        case 2:  // mode 0 - init handle sliders or back btn
          mode_7_2_handle_touch(ui.getItemPressed(p));
          break;
        case 3:  // mode 0 - init handle sliders or back btn
          mode_7_3_handle_touch(ui.getItemPressed(p));
          break;
        case 4:  // mode 0 - init handle sliders or back btn
          mode_7_4_handle_touch(ui.getItemPressed(p));
          break;
        case 5:  // mode 0 - init handle sliders or back btn
          mode_7_5_handle_touch(ui.getItemPressed(p));
          break;
      }
      wastouched = istouched;
    } else {  // Dragging or still touching
      switch (mode_7_function) {
        case 1:  // drag slider if selected.
          mode_7_1_handle_slide();
          break;
        case 2:  // drag slider if selected.
          mode_7_2_handle_slide();
          break;
        case 3:  // drag slider if selected.
          mode_7_3_handle_slide();
          break;
        case 4:  // drag slider if selected.
          mode_7_4_handle_slide();
          break;
        case 5:  // drag slider if selected.
          mode_7_5_handle_slide();
          break;
          // default: // do nothing.
      }
    }
  } else {  // end of istouched
    wastouched = 0;
    lastBtn = 99;
  }
}
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

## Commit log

2023-04-21 Add Rev A of Epoch
    [epoch-bom.ods, epoch-rev-a.brd, epoch-rev-a.sch]
2023-04-22 Added BOM and placement docs.
    [epoch-bom.ods]
2024-01-03 Bill of Materials
2024-01-08 Create tests for motor chip
2024-01-09 Was transferring wrong length in GS register
    [tlc59401.cpp]
2024-01-09 Get rid of old print statements.
2024-01-09 Integrated motor chip TLC59401
2024-01-09 add print TFT settings util
2024-01-10 Add mode 2 (dual motor pairs)
2024-01-10 Remove unused case statements.
2024-01-12 Cycle working for two and four motors.
2024-01-24 Fix cut-paste typos.
2025-04-02 Update glyphs.h
    Newer arduino C++ uses modern binary number reference "0b01010101"
2025-04-02 Update epoch-fw.ino
    Espresif changed how timers are used. Add hook for mode 7.
2025-04-02 Update tlc59401.cpp
    Newer Espresif changed how led control works.
